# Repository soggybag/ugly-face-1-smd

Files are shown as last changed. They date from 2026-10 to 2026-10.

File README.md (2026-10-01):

# Ugly Face 1 (SMD)

A gated, envelope-controlled square-wave synth fuzz for guitar, in a Hammond 1590B. LM386 + TLC555, SMD parts assembled by JLCPCB, panel parts hand-soldered.

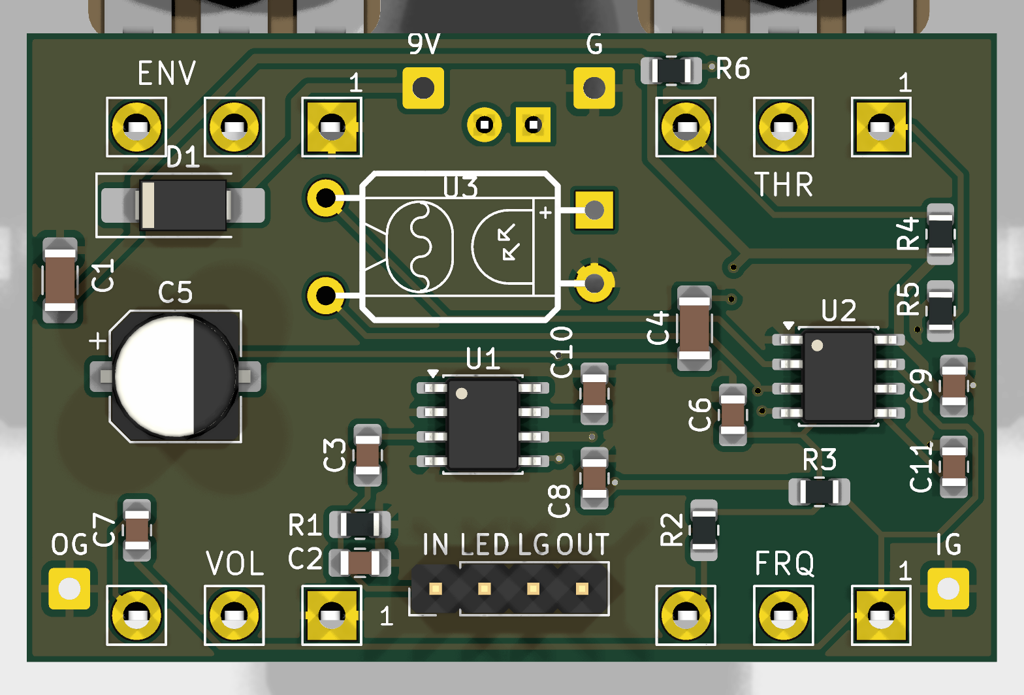
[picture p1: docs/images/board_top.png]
Board, component side


## How it works

The guitar never reaches the output. You hear a **555 square-wave oscillator**, and the guitar controls it in three ways:

1. **Gate.** An LM386 at gain 200 turns the guitar into a clipped square, which drives the 555's RESET pin. The oscillator switches on and off every guitar cycle.
2. **Sync.** Each reset empties the timing capacitor, so the oscillator restarts in step with the note (hard sync).
3. **Pitch bend.** The LM386 output also lights a DIY vactrol (LED + LDR). Its LDR sits across the 555's timing resistor, so playing harder raises the pitch.

Full block-by-block explanation with the maths: [docs/Circuit Walkthrough.md](docs/Circuit%20Walkthrough.md). Schematic: [docs/UglyFace_01_schematic.pdf](docs/UglyFace_01_schematic.pdf).

## Controls

| Knob | Part | Function |
|---|---|---|
| ENV | RV1 B1k | Envelope: how much the playing level drives the vactrol (pitch bend) |
| THR | RV2 B10k | Threshold: 555 RESET bias. Gated / glitchy / always-on |
| FRQ | RV3 C100k | Oscillator frequency (measured ~125 Hz to ~8.3 kHz) |
| VOL | RV4 A100k | Output level |

## Build notes

- **SMD side** (top): assembled by JLCPCB (`production/` outputs are not in the repo; see Releases).
- **Hand-soldered:** four Alpha 16 mm pots and the 3 mm LED (D2) on the **back** (panel side); the DIY vactrol U3 (LED + LDR in heat-shrink); the 4-pin ribbon header J3 (IN, LED−, GND, OUT) to the footswitch board; wire pads 9V/G, IG, OG.
- D2: square pad = cathode (short leg).
- Power: 9 V centre-negative pedal supply; SS14 series reverse-polarity protection. Idle current ~6 mA (+~6 mA LED).

## Status

- v1.1 boards received from JLCPCB 2026-10-01; bench testing in progress. See [docs/Test Sheet.md](docs/Test%20Sheet.md) for measurements.
- Findings and ideas for v2: [docs/Build Notes.md](docs/Build%20Notes.md).

## Repository layout

```
UglyFace_01.kicad_pro / .kicad_sch / .kicad_pcb / .kicad_dru   KiCad 10 project
UglyFace.pretty/, UglyFace.kicad_sym, fp-lib-table, sym-lib-table  project libraries
3dmodels/        pot and enclosure models (referenced via ${KIPRJMOD})
docs/            walkthrough, test sheet, build notes, schematic PDF, renders
enclosure/       panel art (Affinity + PDF/SVG exports)
```

Opens with KiCad 10. All libraries and 3D models are project-local or from KiCad's standard library.

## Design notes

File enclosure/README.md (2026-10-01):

# Enclosure

Hammond 1590B. Panel art and drilling template.

- Keep the Affinity source files here (`.afdesign`; stored with Git LFS).
- **Also commit a PDF or SVG export** of each one, so reviewers without Affinity can see it, and so changes are visible in history.

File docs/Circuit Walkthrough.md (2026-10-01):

# Ugly Face 1 SMD: circuit walkthrough

Board: LM386 + TLC555 version (`UglyFace_01.kicad_sch`, rev 1.1). Refs and values are from the KiCad schematic.
Numbers marked *calc* are hand calculations; confirm them on the bench (see `Test Sheet.md`).

## The big picture

```
IN ─► LM386 (gain 200, hard clipping) ─┬─► 
C4 ─► 555 RESET (gate)   ◄── THRESHOLD sets the bias
                                       └─► C5 ─► ENVELOPE ─► vactrol LED ─► LDR across the 555 timing R
555 astable (FREQUENCY) ─► DISCH ─► C7 ─► VOLUME ─► OUT
```

The guitar never reaches the output. What you hear is the **555's square wave**, which the guitar does three things to:
1. **Gates it.** The clipped guitar signal drives the RESET pin, so the 555 is switched on and off *every guitar cycle*.
2. **Restarts (syncs) it.** Each reset discharges the timing cap, so every time the gate opens the oscillator starts a fresh cycle. That's hard sync to your note, and a lot of the "ugly" character.
3. **Bends its pitch.** The louder you play, the brighter the vactrol LED, the lower the LDR resistance, and the higher the 555 frequency.

---

## Block 1: power and LED

- J1 9V → **D1 SS14** (series Schottky, reverse-polarity protection) → +9V. C1 22µ bulk, C8/C9 100n decoupling at each IC.
- **D2 LED**: +9V → R6 1k → D2 → J3 pin 2 (LED_K) → footswitch to ground.

**Ohm's law: LED current** *calc*
- I = (V+ − V_LED) / R6 = (9.0 − 2.0) / 1k ≈ **7 mA** (for a red LED; ~3 V for blue/white gives ~6 mA).
- The SS14 drops only ~0.2–0.3 V at these currents. That's why a Schottky is used instead of a 1N4001 (~0.7 V).

## Block 2: input and LM386 fuzz

- IN → R1 1M pull-down (stops pops from the coupling cap's DC) → C2 1n to GND (RF filter) → **C3 100n** → U1 pin 3 (+). Pin 2 (−) to GND.
- **U1 pins 1 and 8 are tied directly → gain 200 (46 dB).** C10 10µ on pin 7 (bypass, improves supply rejection).

**What to know about the LM386**
- Inputs are referenced to ground internally through **50k**, so no bias resistors are needed.
- The output idles near **V+/2 ≈ 4.5 V**.

**Input high-pass (C3 with the 50k input resistance)** *calc*
- f = 1 / (2π · R · C) = 1 / (2π · 50k · 100n) ≈ **32 Hz**. The full guitar range passes.

**Gain and clipping** *calc*
- A guitar note of ~100 mV peak × 200 = 20 V peak, far beyond the ~±4 V the output can swing on 9 V.
- So **the LM386 is always hard-clipped:** its output is a near-square copy of your note, about 7–8 Vpp around 4.5 V.
- Shorting pins 1 and 8 *directly* (instead of through a 10µ cap, as the datasheet shows) also raises the **DC** gain. Input offset gets multiplied by 200, so pin 5 may sit noticeably off 4.5 V. That makes the clipping asymmetric. **Measure it**: it's a good real-world lesson.

## Block 3: the gate (THRESHOLD → 555 RESET)

- AMP_OUT → **C4 2.2µ** → RESET node (U2 pin 4).
- RESET is biased by a divider: **+9V → R4 22k → RV2 THRESHOLD B10k → R5 1k → GND**, with the wiper on RESET.

**Divider range** *calc*: V = 9 V · (R below the wiper) / (total 33k)
- Wiper at the R5 end: 9 · 1k / 33k = **0.27 V**.
- Wiper at the R4 end: 9 · 11k / 33k = **3.0 V**.

**How the gate works**
- The TLC555 is held in reset while pin 4 is below its reset threshold (around 1 V; the datasheet gives a range). Above it, the 555 runs.
- THRESHOLD sets the *idle* bias relative to that threshold. The clipped guitar square then pushes RESET above and below it, once per guitar cycle.
  - **Bias well below the threshold:** only the guitar's positive half-cycles open the gate, giving short bursts. The gate is closed when you're not playing.
  - **Bias above the threshold:** the 555 runs all the time (drone), and the guitar's negative half-cycles cut holes in it.

**Gate-coupling high-pass (C4 into the divider's Thevenin resistance)** *calc*
- The divider's source resistance at the wiper is roughly 1k–8k depending on the setting, so f ≈ 1 / (2π · 3k · 2.2µ) ≈ **24 Hz**. The note's fundamental passes.

## Block 4: the envelope (ENVELOPE → vactrol)

- AMP_OUT → **C5 100µ** → RV1 ENVELOPE B1k (pin 3; pin 1 to GND). The wiper drives the **vactrol LED** (U3 pins 1/2) directly.
- The **LDR** (U3 pins 3/4) connects from the 555 output (OSC_SQ) to the timing node, **in parallel with the FREQUENCY resistance**.
- So, while you play:
  1. The positive peaks light the LED, and the LDR resistance drops (from MΩ in the dark to around 1k when bright).
  2. That raises the 555 frequency: louder means higher pitch.
  3. The LDR is slow (tens of ms), so the pitch **swoops** rather than tracking each cycle.
- **Watch-out:** with ENVELOPE at maximum, the LED sits right on C5 with no series resistor, so the only current limit is the LM386's output. Check on the bench that the LED isn't being overdriven (see the test sheet).

## Block 5: the 555 oscillator (FREQUENCY)

- TLC555 (CMOS) in the **"output-driven RC" astable**: the 555's own output (pin 3) charges and discharges **C6 100n** through *(RV3 FREQUENCY between its wiper and pin 3) + R2 470*. Pins 2 and 6 watch the cap. C11 10n decouples CONT (pin 5).
- The cap swings between **⅓ and ⅔ of V+** (3 V ↔ 6 V). Each half-cycle takes R·C·ln 2.

**Frequency** *calc*: f = 1 / (2 · ln 2 · R · C) ≈ 0.72 / (R · C), giving a near-50% square wave.
- R max = 100k + 470: f ≈ 0.72 / (100.5k · 100n) ≈ **72 Hz**.
- R min = 470: f ≈ 0.72 / (470 · 100n) ≈ **15 kHz** (in practice the output's current limit softens the top end).
- **The LDR in parallel lowers R:** for example, a 10k LDR across 50k gives 8.3k, which takes the pitch from ~144 Hz to ~870 Hz.
- RV3 is a **C taper (reverse log)**, which spreads the musical range more evenly across the rotation.

## Block 6: output (DISCH → VOLUME)

- The output is taken from **DISCH (pin 7)**. It's an open-drain switch that pulls low whenever the output is low. R3 100k pulls it up when it's off, so DISCH is a 0–9 V square in step with the output.
- → **C7 100n** → **RV4 VOLUME A100k** → OUT.

**Output high-pass** *calc*
- f = 1 / (2π · 100k · 100n) ≈ **16 Hz**.

**Level** *calc*
- A 9 Vpp square is about **4.5 V RMS (+15 dBu)**, far hotter than a guitar.
- That's why VOLUME is an A (log) taper, and why most of the useful range is at the low end of the knob.

---

## Exercises (try before reading the answers above)

1. LED current with a 9.5 V supply and a 2 V LED, through R6 1k (plus the SS14 drop).
2. The RESET voltage with THRESHOLD at mid-travel (5k on each side of the wiper).
3. If C6 were 47n instead of 100n, what would the FREQUENCY range become?
4. The guitar into the LM386 has a ~32 Hz high-pass. What would change if C3 were 10n?
5. Why does the output need C7 at all? (Hint: what DC voltage does DISCH sit at on average?)

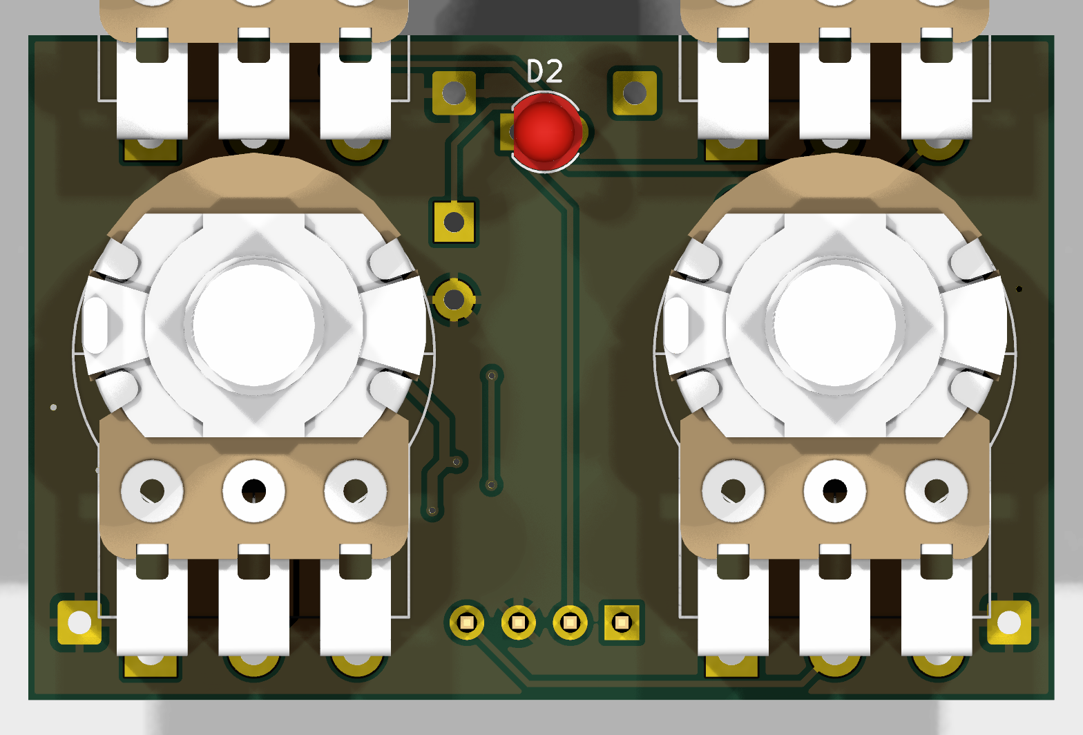
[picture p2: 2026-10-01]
docs/images/board_bottom.png

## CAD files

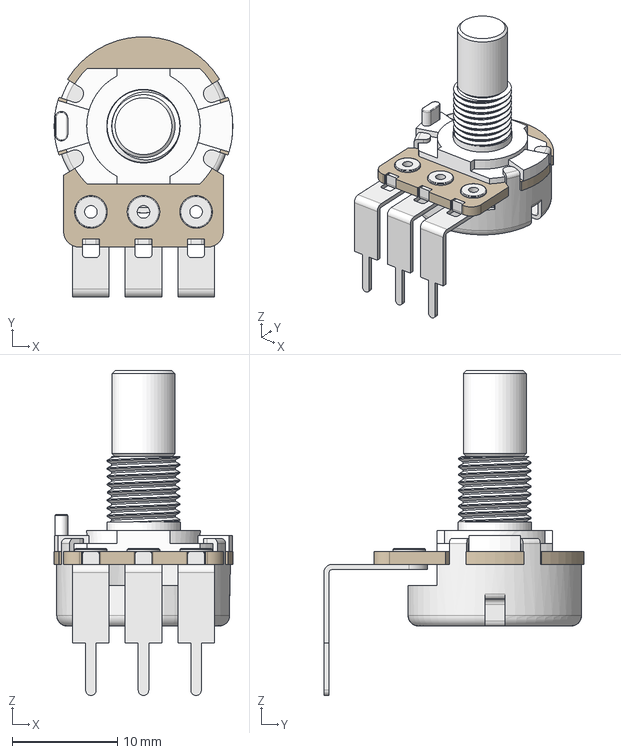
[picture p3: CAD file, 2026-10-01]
3dmodels/RV16AF-41.step
17.0 x 24.7 x 30.9 mm

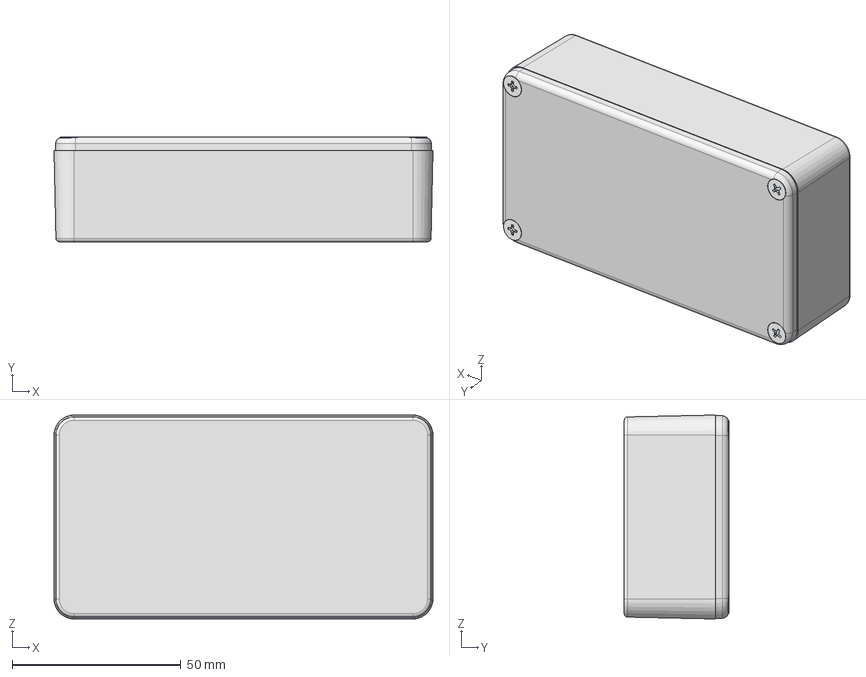
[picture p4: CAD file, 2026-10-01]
3dmodels/1590B.stp
112.4 x 31.0 x 60.5 mm

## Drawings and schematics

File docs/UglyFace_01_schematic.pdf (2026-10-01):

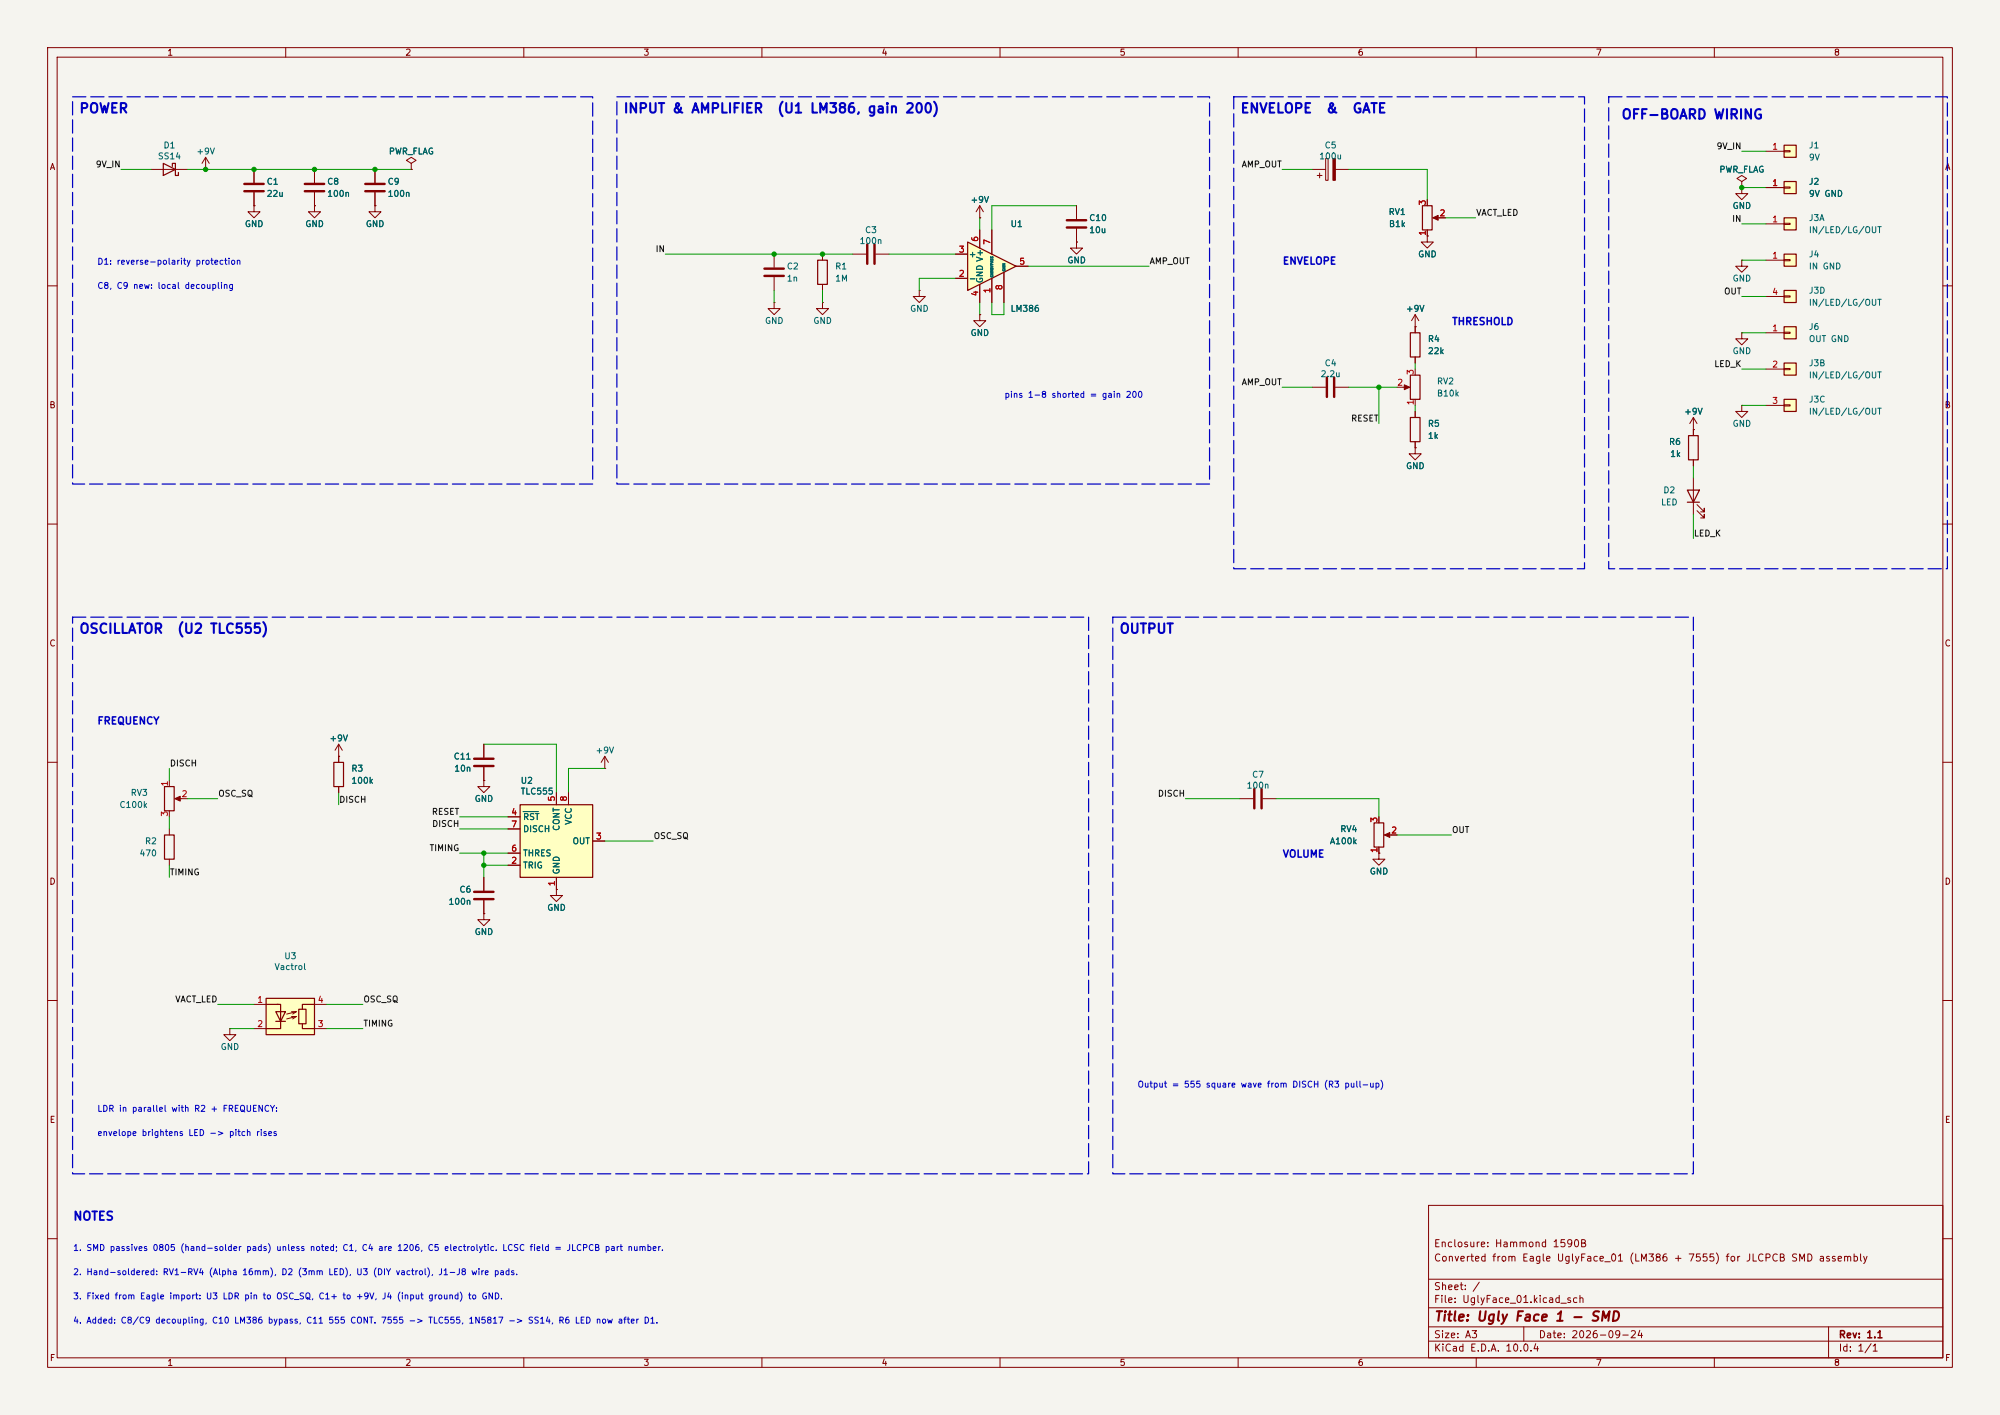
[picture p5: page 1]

IN/LED/LG/OUT C8

IN/LED/LG/OUT C10

IN/LED/LG/OUT R6

AMP_OUT RESET DISCH
LDR in parallel with R2 + FREQUENCY: FREQUENCY

Output = 555 square wave from DISCH (R3 pull-up)

envelope brightens LED -> pitch rises

1. SMD passives 0805 (hand-solder pads) unless noted; C1, C4 are 1206, C5 electrolytic. LCSC field = JLCPCB part number.

Enclosure: Hammond 1590B
Converted from Eagle UglyFace_01 (LM386 + 7555) for JLCPCB SMD assembly

3. Fixed from Eagle import: U3 LDR pin to OSC_SQ, C1+ to +9V, J4 (input ground) to GND. 2. Hand-soldered: RV1-RV4 (Alpha 16mm), D2 (3mm LED), U3 (DIY vactrol), J1-J8 wire pads.

Sheet: /
File: UglyFace_01.kicad_sch
Title: Ugly Face 1 - SMD

Size: A3 | Rev: 1.1 | F Date: 2026-09-24
KiCad E.D.A. 10.0.4 | Id: 1/1

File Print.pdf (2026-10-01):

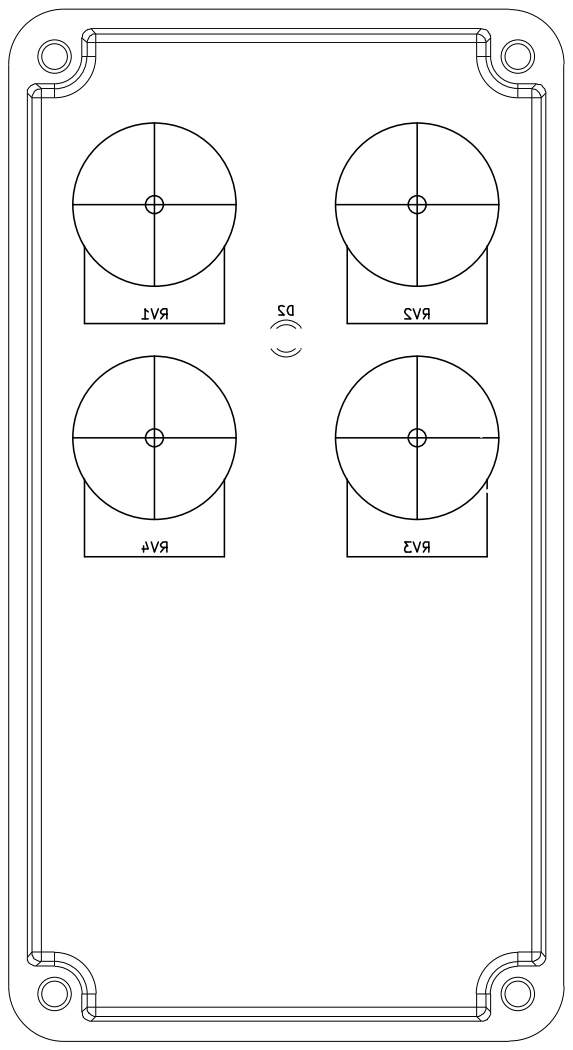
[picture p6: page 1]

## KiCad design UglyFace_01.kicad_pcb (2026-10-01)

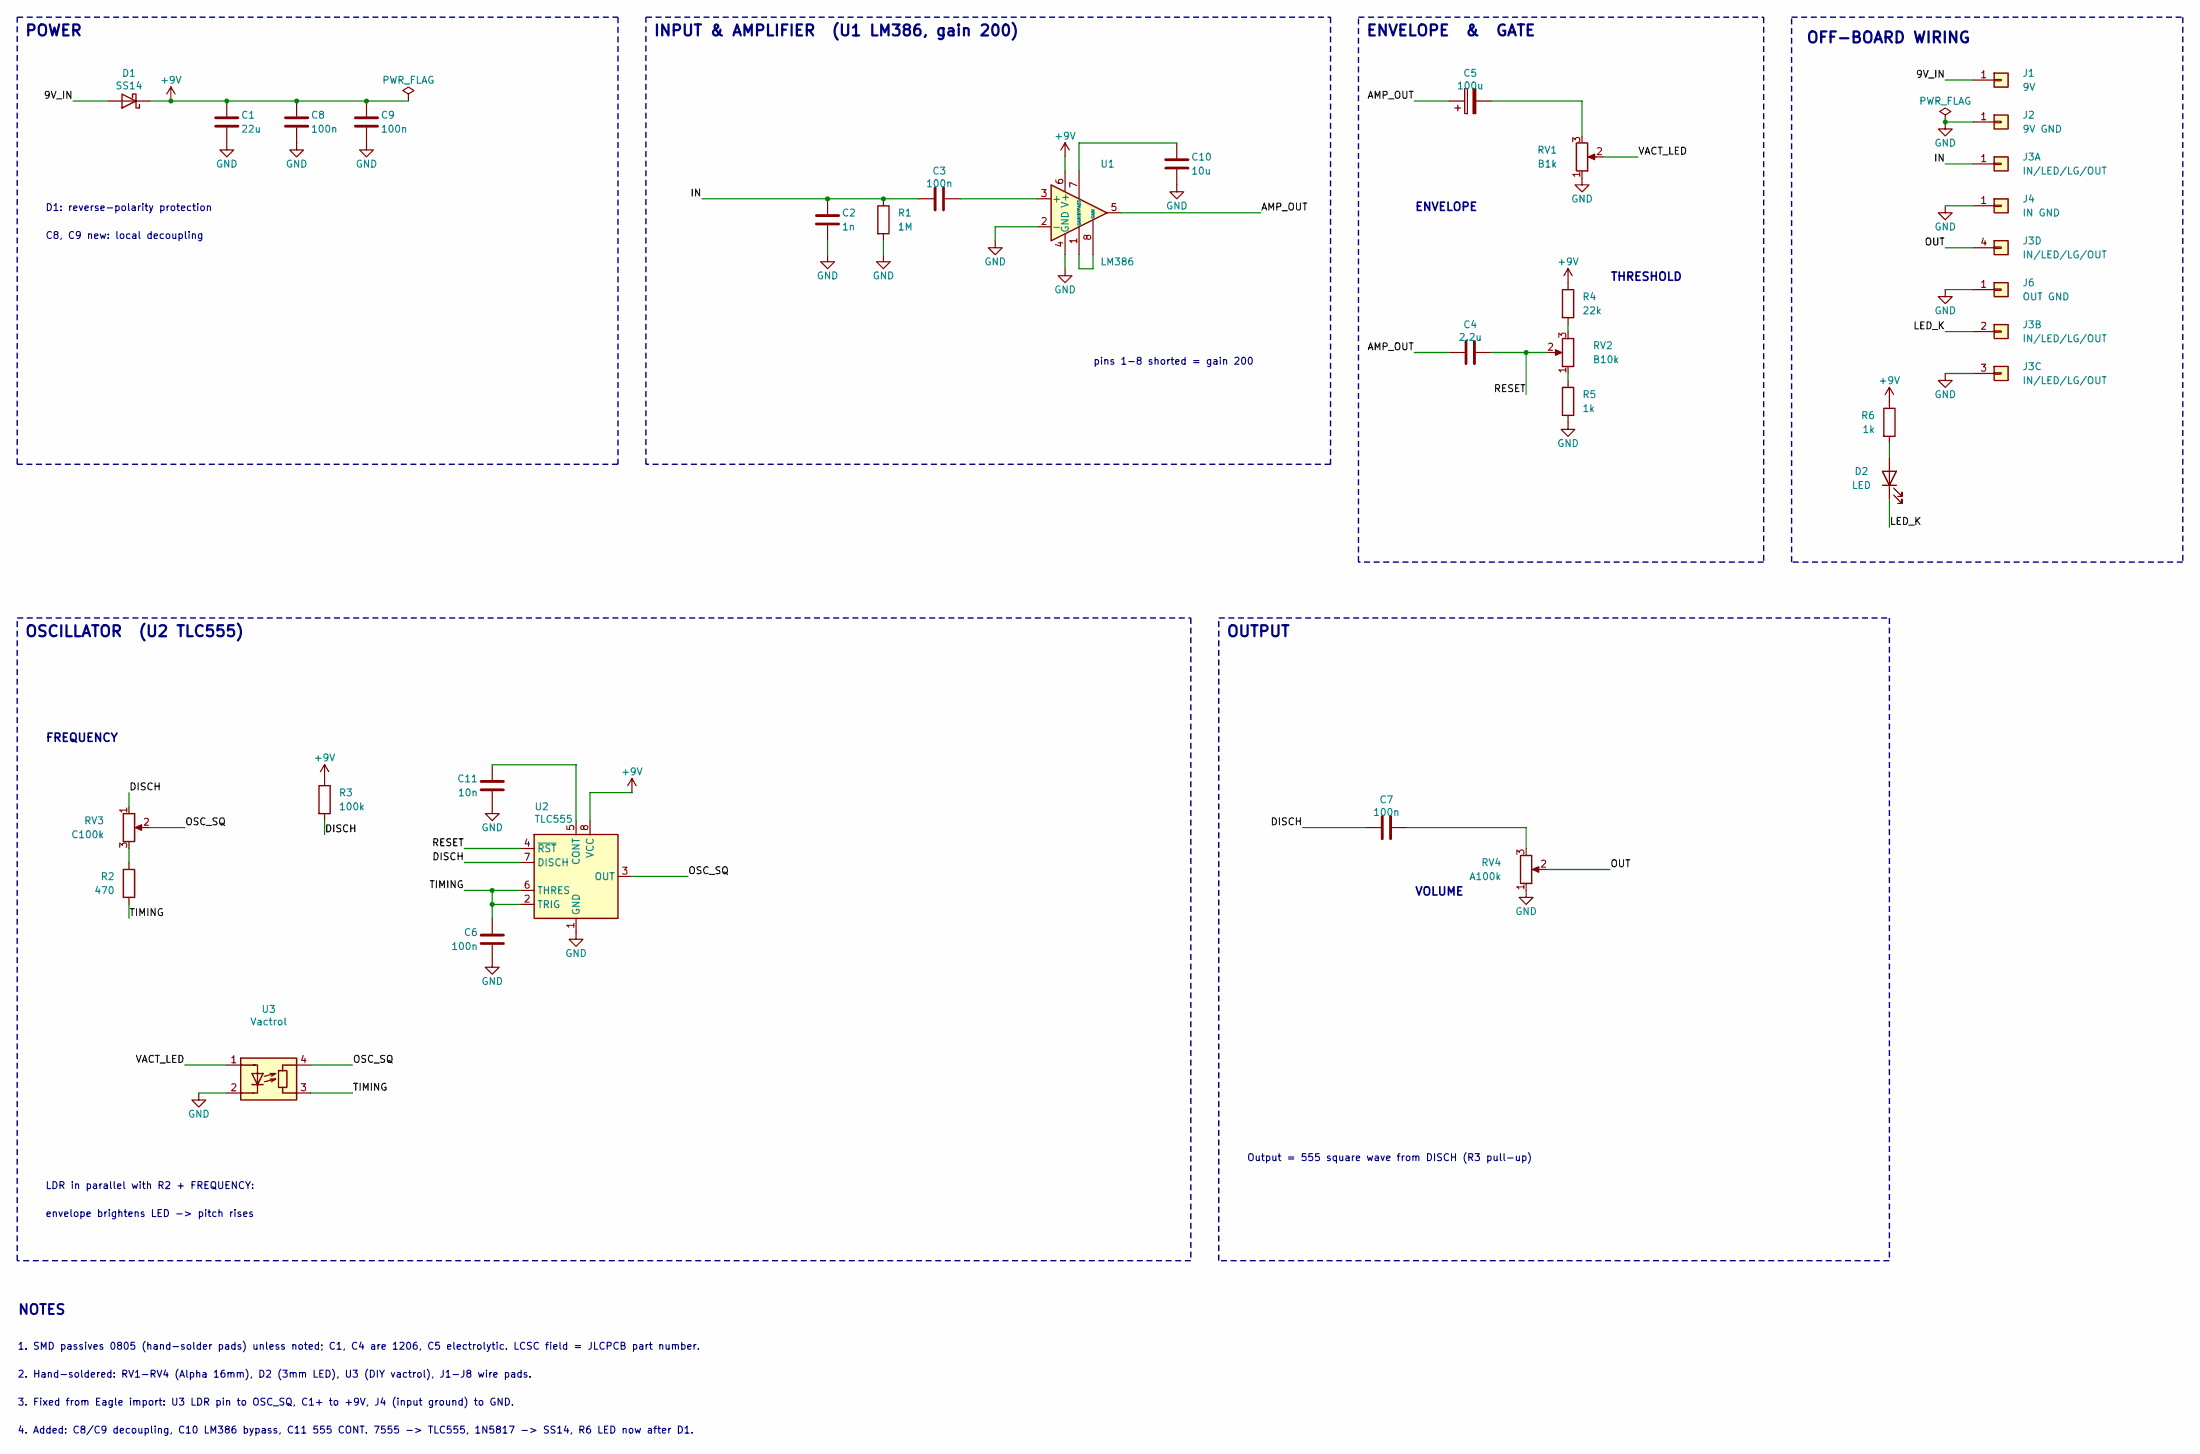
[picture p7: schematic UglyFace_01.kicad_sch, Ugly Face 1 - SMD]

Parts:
C1: 22u; C_1206_3216Metric_Pad1.33x1.80mm_HandSolder; LCSC C12891
C2: 1n; C_0805_2012Metric_Pad1.18x1.45mm_HandSolder; LCSC C46653
C3, C6, C7, C8, C9: 100n; C_0805_2012Metric_Pad1.18x1.45mm_HandSolder; LCSC C49678
C4: 2.2u; C_1206_3216Metric_Pad1.33x1.80mm_HandSolder; LCSC C50254
C5: 100u; CP_Elec_6.3x7.7; LCSC C970685
C10: 10u; C_0805_2012Metric_Pad1.18x1.45mm_HandSolder; LCSC C15850
C11: 10n; C_0805_2012Metric_Pad1.18x1.45mm_HandSolder; LCSC C1710
D1: SS14; D_SMA_Handsoldering; LCSC C2480
D2: LED; LED_D3.0mm
J1: 9V; SolderWire-0.5sqmm_1x01_D0.9mm_OD2.1mm
J2: 9V GND; SolderWire-0.5sqmm_1x01_D0.9mm_OD2.1mm
J3: IN/LED/LG/OUT; PinHeader_1x04_P2.54mm_Vertical
J4: IN GND; SolderWire-0.5sqmm_1x01_D0.9mm_OD2.1mm
J6: OUT GND; SolderWire-0.5sqmm_1x01_D0.9mm_OD2.1mm
R1: 1M; R_0805_2012Metric_Pad1.20x1.40mm_HandSolder; LCSC C17514
R2: 470; R_0805_2012Metric_Pad1.20x1.40mm_HandSolder; LCSC C17710
R3: 100k; R_0805_2012Metric_Pad1.20x1.40mm_HandSolder; LCSC C149504
R4: 22k; R_0805_2012Metric_Pad1.20x1.40mm_HandSolder; LCSC C17560
R5, R6: 1k; R_0805_2012Metric_Pad1.20x1.40mm_HandSolder; LCSC C17513
RV1: B1k; Potentiometer_Alpha_16mm_Vertical
RV2: B10k; Potentiometer_Alpha_16mm_Vertical
RV3: C100k; Potentiometer_Alpha_16mm_Vertical
RV4: A100k; Potentiometer_Alpha_16mm_Vertical
U1: LM386; SOIC-8_3.9x4.9mm_P1.27mm; LCSC C23573
U2: TLC555; SOIC-8_3.9x4.9mm_P1.27mm; LCSC C6987
U3: Vactrol; Vactrol_LED_LDR_DIY

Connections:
/9V_IN: D1.2 (A), J1.1 (Pin_1_1)
/AMP_OUT: C4.1, C5.1, U1.5
/DISCH: C7.1, R3.2, RV3.1, U2.7 (DISCH)
/IN: C2.1, C3.1, J3.1, R1.1
/LED_K: D2.1 (K), J3.2
/OSC_SQ: RV3.2, U2.3 (OUT), U3.4 (R)
/OUT: J3.4, RV4.2
/RESET: C4.2, RV2.2, U2.4 (~RST)
/TIMING: C6.1, R2.2, U2.2 (TRIG), U2.6 (THRES), U3.3 (R)
/VACT_LED: RV1.2, U3.1 (A)
unnamed: C5.2, RV1.3
unnamed: C7.2, RV4.3
unnamed: D2.2 (A), R6.2
unnamed: R2.1, RV3.3
unnamed: R4.2, RV2.3
unnamed: R5.1, RV2.1
unnamed: C3.2, U1.3 (+)
unnamed: C10.1, U1.7 (BYPASS)
unnamed: U1.1 (GAIN), U1.8 (GAIN)
unnamed: C11.1, U2.5 (CONT)

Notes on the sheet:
pins 1-8 shorted = gain 200
4. Added: C8/C9 decoupling, C10 LM386 bypass, C11 555 CONT. 7555 -> TLC555, 1N5817 -> SS14, R6 LED now after D1.
NOTES
THRESHOLD
C8, C9 new: local decoupling
Output = 555 square wave from DISCH (R3 pull-up)
POWER
2. Hand-soldered: RV1-RV4 (Alpha 16mm), D2 (3mm LED), U3 (DIY vactrol), J1-J8 wire pads.
VOLUME
ENVELOPE & GATE
ENVELOPE
LDR in parallel with R2 + FREQUENCY:
3. Fixed from Eagle import: U3 LDR pin to OSC_SQ, C1+ to +9V, J4 (input ground) to GND.
D1: reverse-polarity protection
FREQUENCY
1. SMD passives 0805 (hand-solder pads) unless noted; C1, C4 are 1206, C5 electrolytic. LCSC field = JLCPCB part number.
OFF-BOARD WIRING
envelope brightens LED -> pitch rises
OSCILLATOR (U2 TLC555)
OUTPUT
INPUT & AMPLIFIER (U1 LM386, gain 200)

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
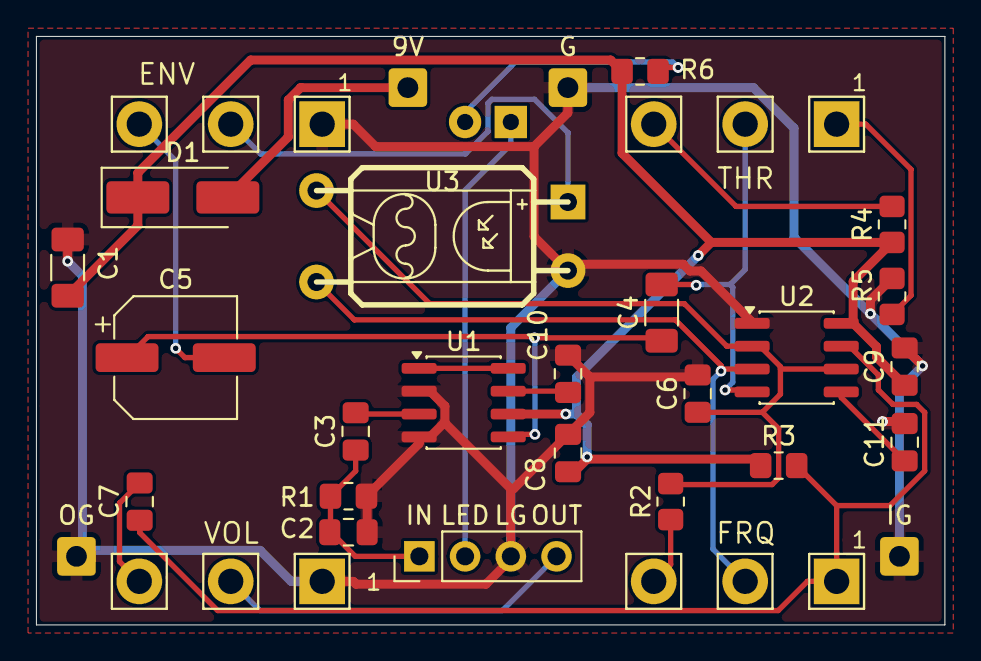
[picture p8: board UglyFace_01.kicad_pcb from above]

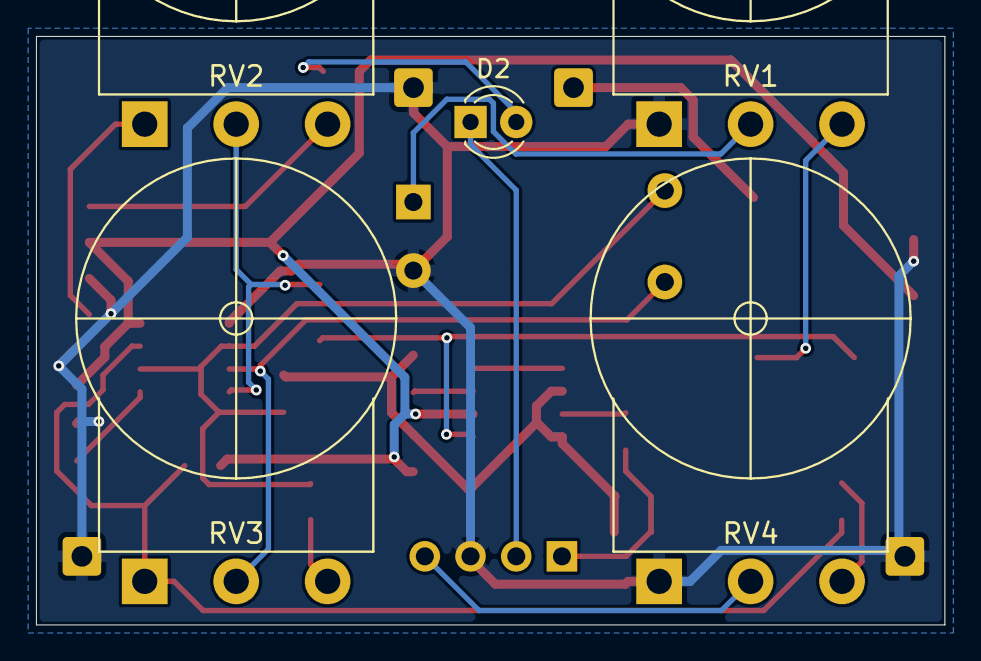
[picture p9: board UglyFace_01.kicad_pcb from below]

Board: 2 copper layers, 50.5 x 32.7 mm, 32 parts (2 on the bottom side), 22 nets.

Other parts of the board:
ENC1: Hammond 1590B; Hammond_1590B

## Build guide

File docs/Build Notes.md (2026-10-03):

# Ugly Face 1 SMD: build notes and v2 ideas

Findings from bench testing (see `Test Sheet.md` for the measurements).

## THRESHOLD acts like a 3-position switch, not a range (2026-10-01)

- Measured: RESET bias range 0.28–2.63 V; TLC555 reset threshold = **1.0 V**, crossed at ~30% rotation.
- In use, the knob gives **three behaviours** rather than a smooth range:
  1. **Gated:** bias well below 1 V. Silent at idle; the 555 only runs on the guitar's positive swings.
  2. **Glitchy:** bias right at ~1 V. The gate chatters on the edge, giving unstable, broken-up bursts.
  3. **On:** bias well above 1 V. The 555 drones; playing cuts holes in it.
- **v2 idea: replace RV2 with a 3-position switch** (ON-ON-ON toggle, or a SP3T slide/rotary):
  - GATED: RESET biased ~0.3 V (as now at CCW).
  - GLITCH: RESET biased at the threshold. **Make this a trimmer**, because the reset threshold varies from chip to chip (datasheet range; this one is 1.0 V).
  - ON: RESET biased ~2.5–3 V.
  - Keep C4 coupling the guitar onto RESET in all positions. Keep the bias source impedance in the low kΩ so the C4 high-pass (~24 Hz) stays put.
- This frees a panel position (e.g. for a dry/blend or a second oscillator control).

## Other v2 items from testing

- **DISCH output is loaded:** it averages 3.27 V instead of ~4.4 V, because R3 100k pulls up against VOLUME 100k through C7. Lower R3 (≈10k), or take the output from pin 3 (push-pull) through a resistor.
- **FREQUENCY top end limited by the TLC555 output resistance:** R2 470 Ω is comparable to the output's few hundred Ω, so the top is 8.3 kHz, not 15 kHz, and the square sags at CW. Raise R2 (≈1k) for a cleaner top end, or accept it.
- **Vactrol LED has no series resistor** at ENVELOPE max (LED directly on C5 / LM386 output). Check the current in the section 4 tests; add ~100–220 Ω if it's high.
- **FREQUENCY low end:** 125 Hz measured vs ~72 Hz predicted, with 104k measured from pin 3 to pin 2 (so the resistance is fine). Open: C6 value or the scope timebase reading (see the test sheet).

## Protecting the CMOS 555 (2026-10-02)

The user has had 7555s die occasionally in past builds. CMOS inputs are damaged by being pulled **outside the supply rails** (below GND or above V+). Each pin has internal protection diodes to the rails. When one conducts, current is injected into the chip's substrate, which can trigger **latch-up**: a parasitic short across the supply that burns the chip unless the current is limited. Limits: inputs from −0.3 V to V+ + 0.3 V; supply ≤ 18 V (TLC555 / ICM7555).

**Where this board can do that (most likely first):**

1. **RESET (pin 4) is driven below ground on every guitar cycle.**
   - The fuzz stage swings about ±3.5 V around its bias and is AC-coupled (C4 2.2µ on UF1, C9 on UF3) onto a RESET bias of only 0.1–2.6 V. The negative half pushes pin 4 down to about −3 V.
   - The pin's internal diode to GND clamps it at about −0.6 V. The current is limited only by the fuzz stage's output (tens of mA). That's substrate injection every cycle.
   - **Worst at power-down / unplugging:** the coupling cap still holds its charge while the fuzz output falls to 0 V, driving pin 4 several volts negative.
   - The clamp also *rectifies*: C4/C9 charge until the negative peaks sit at −0.6 V, which shifts the effective gate bias. That's part of how THRESHOLD actually behaves.
2. **UF1 only: DISCH (pin 7) drives the output jack** through C7 100n and VOLUME, with no buffer. A static zap or plugging transient on the OUT jack goes straight to the 555 pin. (UF3 is safe here: U1B buffers the output and R18 100 Ω isolates it.)
3. **Power-down:** C10/C6 (timing) and the other caps on 555 pins discharge back into the pins as V+ collapses. This is small energy, normally fine.
4. **Supply over-voltage:** SS14 protects against reverse polarity only. A 12–18 V adapter is within the 555's 18 V limit, but **UF1's LM386 is only rated to 15 V** (the TL072 on UF3 is fine).

**Precautions for the next revision:**

- **Series resistor into RESET: 10k–47k between the bias/coupling node and pin 4.**
  - RESET draws only pA, so the bias and the sound don't change.
  - The clamp current drops from tens of mA to < 0.5 mA.
  - This is the single most useful fix. One 0805 resistor.
- **Optional Schottky clamp** (BAT54S, one diode to GND and one to V+) on the node *before* that resistor, so the external diode takes the current instead of the chip.
  - Note: clamping is already happening inside the chip, so this keeps today's sound (the same −0.3 to −0.6 V DC-restore). It just moves the stress outside.
- **UF1: don't drive the jack from the 555 directly.** Add ~1k in series at minimum, or buffer it as UF3 does.
- **Optional over-voltage TVS** across the supply after D1 (e.g. SMAJ15A, or a 15 V zener with the SS14 acting as the series element), mainly for UF1's LM386.
- **Prefer the TLC555 (TI LinCMOS)** over generic ICM7555 clones; keep the 100n at pin 8 close to the chip (already done).
- Both boards already have the C11 10n on CONT, decoupling at pin 8, and series reverse-polarity protection.

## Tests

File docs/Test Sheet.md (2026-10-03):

# Ugly Face 1 SMD: test sheet

Gear: multimeter, oscilloscope, audio probe. Expected values are hand calculations (see `Circuit Walkthrough.md`).
Record the supply voltage first. Every expected value scales with it.

## 0. Before power

| Check | Expected | Measured | OK |
|---|---|---|---|
| Visual: U1/U2 pin-1 dots, D1 band, C5 polarity, vactrol LED orientation | as silkscreen | - | x |
| Short check: ohms, red on J1 (9V pad), black on GND | starts low and climbs while C1 charges, then settles at tens of kΩ or more. **Fail: near 0 Ω or a steady few Ω** | 4K | x |
| Same with the leads swapped (black on J1) | OL / very high (D1 blocks) | - | x |
| Short check: ohms, red on +9V (D1 cathode), black on GND | climbs, then settles at tens of kΩ (the 33k THRESHOLD divider in parallel with the ICs) | 27K | x |
| D1 diode test (red on J1, black on cathode) | 0.15–0.3 V | 200mv | x |

## 1. First power (no input, footswitch off, all knobs at noon)

Use a current-limited supply, or 9 V through a 100 Ω resistor (each 1 mA shows as 0.1 V across it).

| Check | Expected | Measured | OK |
|---|---|---|---|
| Supply voltage at J1 | ~9.0–9.6 V | 7.94V | x |
| Current draw, LED off | **~5 mA** (LM386 ≈ 4 mA + dividers) | 0.6v | x |
| Current draw, LED on (LED_K to GND) | **~11–12 mA** (+ ~7 mA LED) | 1.17V | x |
| Current with FREQUENCY at max pitch and the gate open | rises a few mA (555 driving C6 through 470 Ω) | 1.46V | x |

## 2. DC voltages (black probe on GND)

| Node | Where | Expected | Measured |
|---|---|---|---|
| +9V | D1 cathode / U1 pin 6 / U2 pin 8 | supply − 0.2–0.3 V | 8.8V |
| LED anode (LED on) | D2 + / R6 | ~2 V (red) | 1.96V |
| U1 pin 3 (+in) | | ~0 V | 0.01V |
| U1 pin 5 (AMP_OUT) | | **~4.5 V** (pins 1–8 shorted: may be off by up to ~1 V; note it) | 4.41V |
| U1 pin 7 (bypass) | | a few volts (record) | 4.44V |
| U2 pin 4 (RESET), THRESHOLD full CCW | | ~0.27 V *or* ~3.0 V (depends on pot orientation) | 2.63V |
| U2 pin 4 (RESET), THRESHOLD full CW | | the other end: ~3.0 V / ~0.27 V | 0.28V |
| U2 pin 5 (CONT) | | **6.0 V** (⅔ V+) | 5.86V |
| U2 pins 2/6 (TIMING), 555 running | | ~4.5 V average (DMM); scope: 3 V ↔ 6 V | 4.41V |
| U2 pin 3 (OSC_SQ), running / held in reset | | ~4.5 V avg / 0 V | 4.45V |
| U2 pin 7 (DISCH), running / held in reset | | ~4.5 V avg / 0 V | 3.27V |
| Vactrol LED anode (no signal) | RV1 wiper | 0 V | 0V |

## 3. Experiment: find the TLC555 reset threshold

1. No input. Scope (or audio probe) on OUT or U2 pin 3.
2. Turn THRESHOLD slowly from the low-voltage end until the 555 **just starts** oscillating.
3. Measure U2 pin 4 at that point. **That's the real reset threshold** (expected ~1 V; the datasheet allows a range).

| Reset threshold (V) | |
|---|---|
|  | 1V |

## 4. Signal tests (scope; guitar or a ~200 mVpp 200 Hz sine into IN)

| Point | Expected | Seen |
|---|---|---|
| U1 pin 5 (AMP_OUT) | clipped square, ~7–8 Vpp around ~4.5 V (note the symmetry) |  |
| U2 pin 4 (RESET) | the same square, AC-coupled, centered on the THRESHOLD bias |  |
| U2 pins 2/6 (TIMING) | exponential ramps 3 ↔ 6 V; restarting from 0 V each time the gate opens (sync) | |
| U2 pin 7 / OUT | 555 square bursts, gated per guitar cycle | |
| FREQUENCY min / max (gate held open, no LDR light) | ~72 Hz / several kHz (record the actual values) | 125 Hz to 16.7 kHz |
| Vactrol LED anode, ENVELOPE max, strong signal | positive half-cycles ~1.8–2 V (LED clamps) | |
| Pitch change with playing level (ENVELOPE up) | louder → higher pitch, with a slow swoop | |

**Vactrol LED drive check:** put the 100 Ω series resistor (from section 1) in series with the supply and compare the current with ENVELOPE at 0 vs max under a strong signal. A large jump (tens of mA) means the LED is being driven hard; we'd then add a series resistor in v2.

## 5. Audio probe trace (cap-coupled probe, low volume)

IN → U1 pin 3 → U1 pin 5 (loud fuzz) → U2 pin 4 (gated fuzz) → U2 pin 3 (synth tone) → OUT (volume-scaled).

## Notes / surprises

- **Section 1 (2026-10-01):** idle 6.0 mA, LED +5.7 mA, 555 at max pitch +2.9 mA.
  - From I = C·ΔV·f, the 555's extra current predicts the max-pitch frequency: f ≈ 2.9 mA / (100n × 2.6 V) ≈ **11 kHz**. Verify on the scope.
- **U1 pin 5 = 4.41 V with +9V = 8.8 V**, which is exactly V+/2. Shorting the LM386's pins 1 and 8 directly did *not* shift the bias on this chip. The predicted offset didn't appear.
- **THRESHOLD range 0.28–2.63 V (predicted 0.27–2.93 V at 8.8 V).** Solving 8.8·(1k + P)/(23k + P) = 2.63 gives **RV2 ≈ 8.4k**, within the ±20% tolerance of a 10k pot. The bottom end (8.8·1k/31.4k = 0.28 V) agrees.
- **CONT 5.86 V** = ⅔ × 8.8 ✓. **TIMING 4.41 V** = midpoint of 2.93 ↔ 5.87 ✓. **OSC_SQ 4.45 V** ≈ 50% duty ✓.
- **DISCH 3.27 V (expected ~4.4 V): this is loading.**
  - DISCH only pulls *down*. Going high, it is pulled up by R3 100k (in parallel with part of the FREQUENCY pot), against VOLUME's 100k load through C7.
  - That divider stops the output square reaching the full 8.8 V. The high level comes out at roughly 6.5–7 V, so the average is ~3.3 V.
  - Prediction: the DISCH average changes with the FREQUENCY setting (stronger pull-up when the wiper is near pin 1). Scope DISCH to see the reduced high level.
  - v2 idea: lower R3 (e.g. 10k), or take the output from pin 3 (push-pull) through a resistor.

- **Oscillator range (scope on U2 pin 3, 8.6 Vpp square):**
  - FREQUENCY CCW: 4 div × 2 ms = 8 ms, **125 Hz** (predicted ~72 Hz).
  - FREQUENCY CW: 12 div × 10 µs = 120 µs, **8.3 kHz** (predicted ~15 kHz with only R2 470 Ω).
  - **CW runs slow:** the TLC555 output has a few hundred Ω of internal resistance, which adds to R2. R_eff = 0.72 / (8.3k × 100n) ≈ 870 Ω, so the output is ≈ 400 Ω. Check: the square's top and bottom should sag visibly at CW.
  - Section 1 current cross-check: C·ΔV·f = 100n × 2.6 V × 8.3 kHz ≈ 2.2 mA vs 2.9 mA measured, so that method agreed better than first thought.
  - **CCW runs fast:** the effective timing R ≈ 0.72 / (125 × 100n) ≈ 58k instead of 100.5k.
    - Covering the vactrol made no change, so it's not room light reaching the LDR.
    - Suspects: the LDR's *dark* resistance (it may be only ~100–200k), a low-reading RV3, or C6 under value.
    - Next test: power off, FREQUENCY CCW, ohms from U2 pin 3 to U2 pin 2. Expect ~100k if nothing is in parallel.
- **TLC555 reset threshold = 1.0 V** (section 3).
  - On THRESHOLD: 8.8 × (1k + x) / 31.4k = 1.0 gives x ≈ 2.6k of the 8.4k track, so the gate opens at about **30% rotation**.
  - Below that it idles closed (silent until you play); above it, it drones.
- **U2 pin 3 → pin 2, power off, FREQUENCY CCW: 104k** (RV3 + R2 ≈ 100.5k expected). So the timing resistance is right, and neither the LDR nor anything else is in parallel.
  - The fast low end must then come from **C6** (125 Hz would imply C ≈ 0.70 / (125 × 104k) ≈ 54n) **or the CCW timebase reading** (the Time/DIV knob was between detents earlier).
  - To do: re-time CCW with the knob clicked in (or a tuner app on OUT: 72 Hz ≈ D2, 125 Hz ≈ B2), then measure C6 in capacitance mode.
- **CW square shows sag on the top**, confirming the TLC555's output resistance.

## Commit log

2026-10-01 Ugly Face 1 SMD v1.1: KiCad project, docs and bench notes
    KiCad 10 project (LM386 + TLC555, 1590B) as ordered from JLCPCB, with
    project-local libraries and 3D models, schematic PDF, board renders,
    circuit walkthrough, test sheet and build notes from first bring-up.
    [1590B.stp, RV16AF-41.step, UglyFace_01.kicad_pcb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]
2026-10-07 Archive v1.0 and v1.2: schematic and board PDFs, renders, interactive BOM, parts list, docs and fab files
2026-10-13 Ugly Face 1: v1.2 test sheet and 555 debug notes, v1.2 KiCad archive, Envelope A breadboard, toggle slot footprint, vactrol LED resistor note
2026-10-14 UF1 v1.2: Schottky clamp on 555 RESET tested (pin 4 held at -0.2 / +9.2 V, no audible change); adopt for retrofit and next revision
2026-10-14 UF1 build notes: protection summary table (R9 + Schottky clamp, R10, D1)
